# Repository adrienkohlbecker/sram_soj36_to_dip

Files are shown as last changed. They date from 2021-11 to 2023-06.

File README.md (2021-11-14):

# sram_soj36_to_dip

This project converts an IS61C5128AL (SOJ-36) SRAM to an AS6C4008 (DIP-32) SRAM. It includes pinout conversion so the final pinout is the one of a AS6C4008 chip, allowing drop-in replacement with a faster chip (eg. 55ns to 10ns). Hand-soldering the chip is doable with a thin solder wire (I used 0.38mm solder wire for this). A spot for a 0.1uF decoupling capacitor is also provided.

## End result

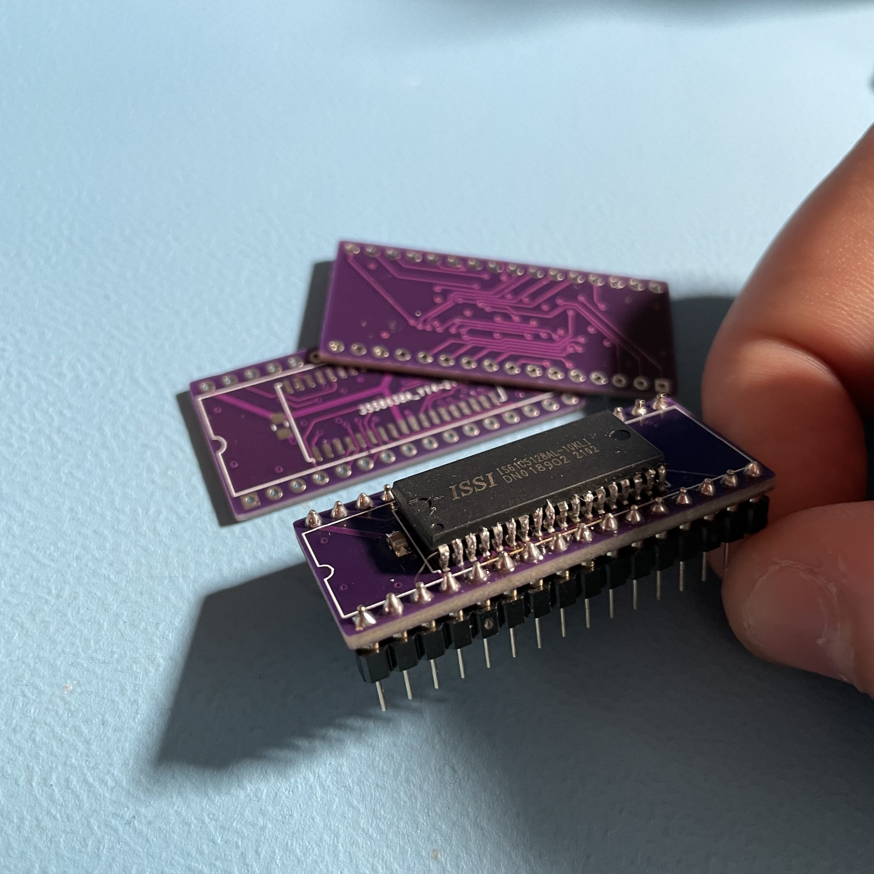
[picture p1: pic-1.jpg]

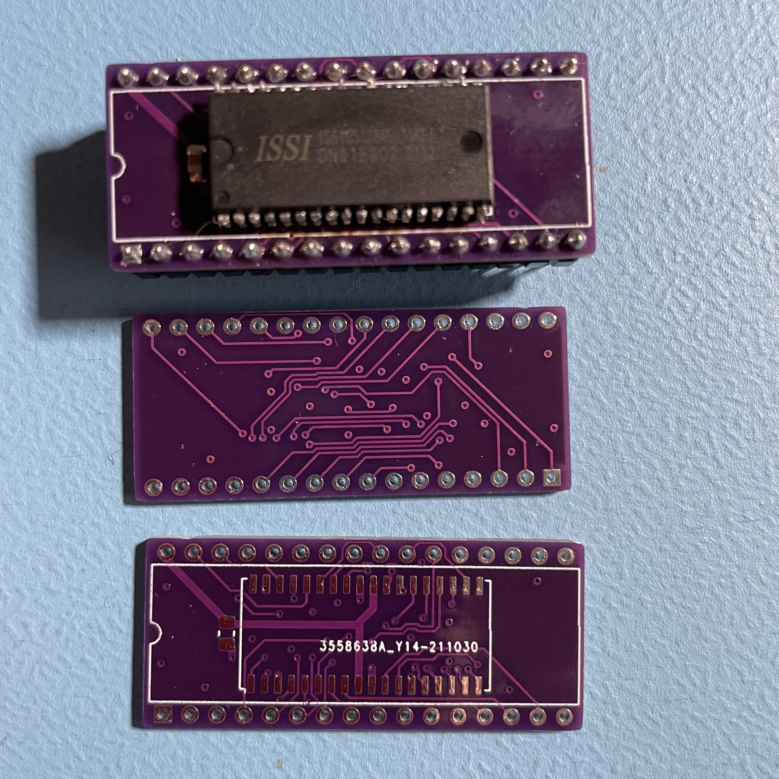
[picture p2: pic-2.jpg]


## Schematic

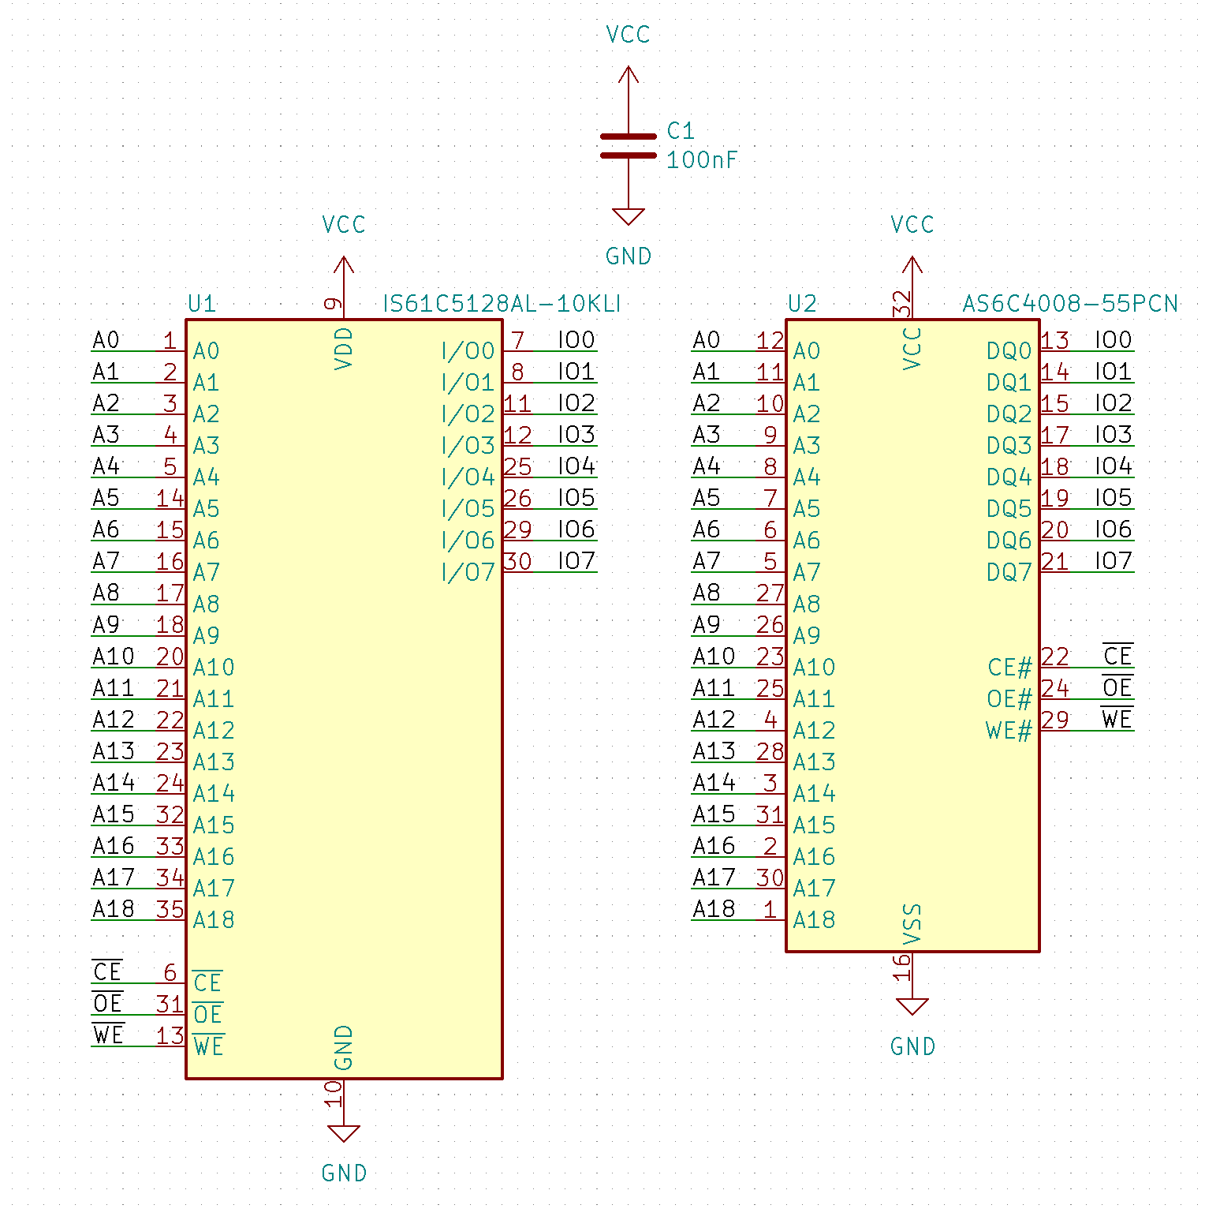
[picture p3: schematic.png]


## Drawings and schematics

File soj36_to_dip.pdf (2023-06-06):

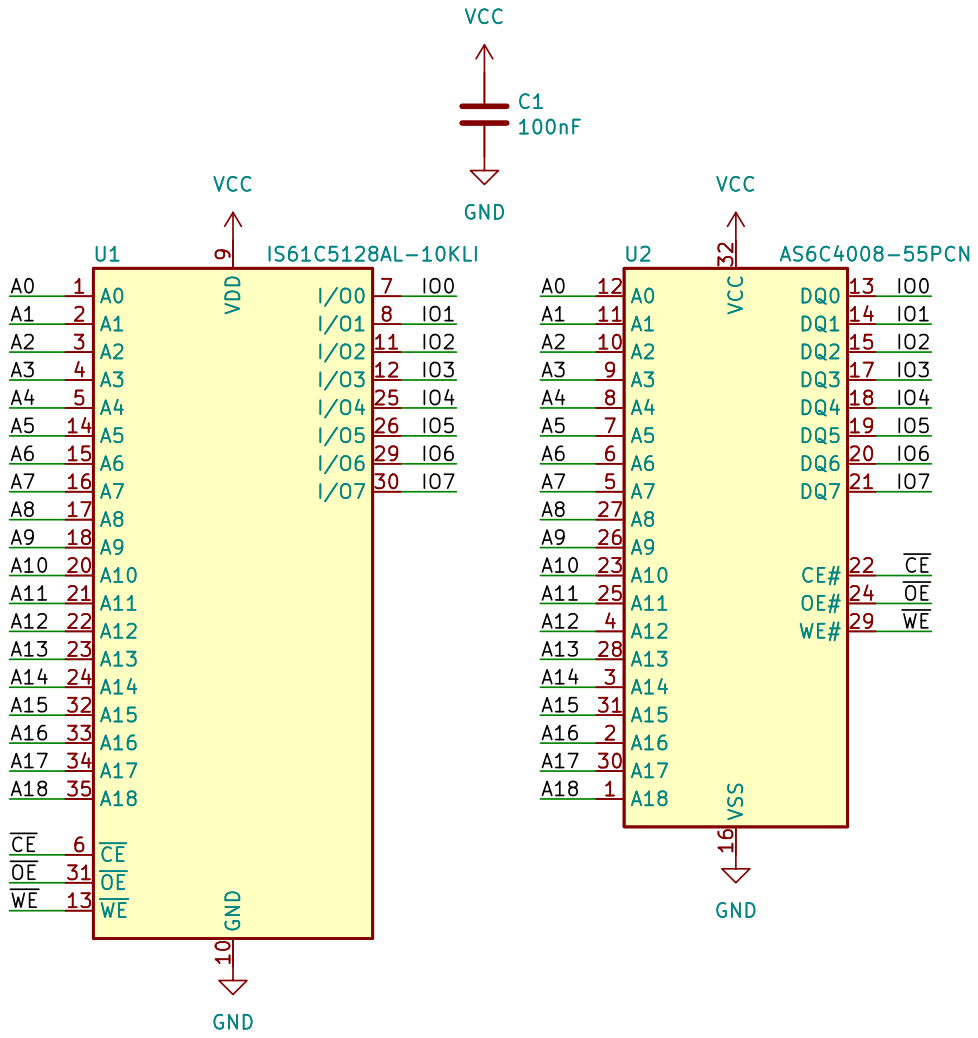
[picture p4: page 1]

Id: 1/1 Title: SRAM SOJ36 to DIP

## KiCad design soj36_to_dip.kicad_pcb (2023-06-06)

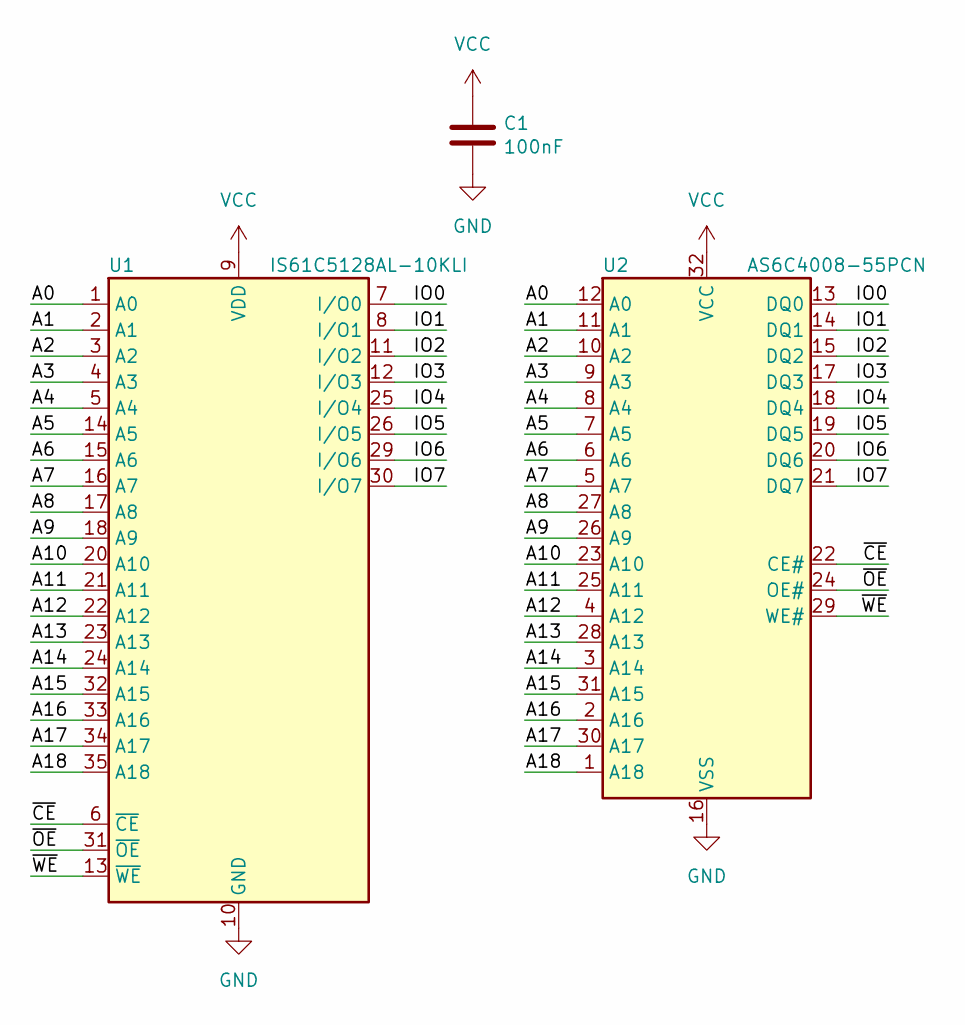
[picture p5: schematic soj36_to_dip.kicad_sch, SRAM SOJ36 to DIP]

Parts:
C1: 100nF; C_0805_2012Metric_Pad1.18x1.45mm_HandSolder
U1: IS61C5128AL-10KLI; SOJ-36_10.16x23.49mm_P1.27mm
U2: AS6C4008-55PCN; DIP-32_W15.24mm

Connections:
A0: U1.1 (A0), U2.12 (A0)
A1: U1.2 (A1), U2.11 (A1)
A2: U1.3 (A2), U2.10 (A2)
A3: U1.4 (A3), U2.9 (A3)
A4: U1.5 (A4), U2.8 (A4)
A5: U1.14 (A5), U2.7 (A5)
A6: U1.15 (A6), U2.6 (A6)
A7: U1.16 (A7), U2.5 (A7)
A8: U1.17 (A8), U2.27 (A8)
A9: U1.18 (A9), U2.26 (A9)
A10: U1.20 (A10), U2.23 (A10)
A11: U1.21 (A11), U2.25 (A11)
A12: U1.22 (A12), U2.4 (A12)
A13: U1.23 (A13), U2.28 (A13)
A14: U1.24 (A14), U2.3 (A14)
A15: U1.32 (A15), U2.31 (A15)
A16: U1.33 (A16), U2.2 (A16)
A17: U1.34 (A17), U2.30 (A17)
A18: U1.35 (A18), U2.1 (A18)
GND: C1.2, U1.10 (GND), U1.28 (GND), U2.16 (VSS)
IO0: U1.7 (I/O0), U2.13 (DQ0)
IO1: U1.8 (I/O1), U2.14 (DQ1)
IO2: U1.11 (I/O2), U2.15 (DQ2)
IO3: U1.12 (I/O3), U2.17 (DQ3)
IO4: U1.25 (I/O4), U2.18 (DQ4)
IO5: U1.26 (I/O5), U2.19 (DQ5)
IO6: U1.29 (I/O6), U2.20 (DQ6)
IO7: U1.30 (I/O7), U2.21 (DQ7)
VCC: C1.1, U1.9 (VDD), U1.27 (VDD), U2.32 (VCC)
~CE: U1.6 (~CE), U2.22 (CE#)
~OE: U1.31 (~OE), U2.24 (OE#)
~WE: U1.13 (~WE), U2.29 (WE#)

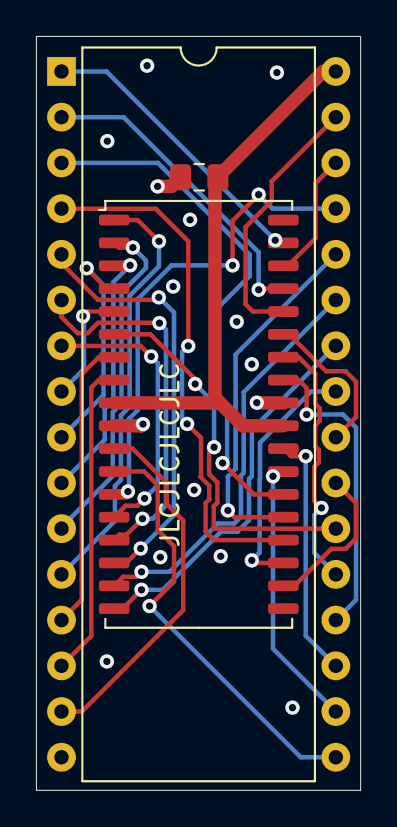
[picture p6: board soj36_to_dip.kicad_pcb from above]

Board: 4 copper layers, 18.0 x 41.9 mm, 3 parts (0 on the bottom side), 32 nets.

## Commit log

2021-11-14 Publish project
    [soj36_to_dip-B_Cu.gbl, soj36_to_dip-B_Mask.gbs, soj36_to_dip-B_Paste.gbp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]
2021-11-14 Add documentation
    [soj36_to_dip.sch]
2023-06-06 Update for KiCad 6
    [soj36_to_dip-B_Cu.gbl, soj36_to_dip-B_Mask.gbs, soj36_to_dip-B_Paste.gbp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]
